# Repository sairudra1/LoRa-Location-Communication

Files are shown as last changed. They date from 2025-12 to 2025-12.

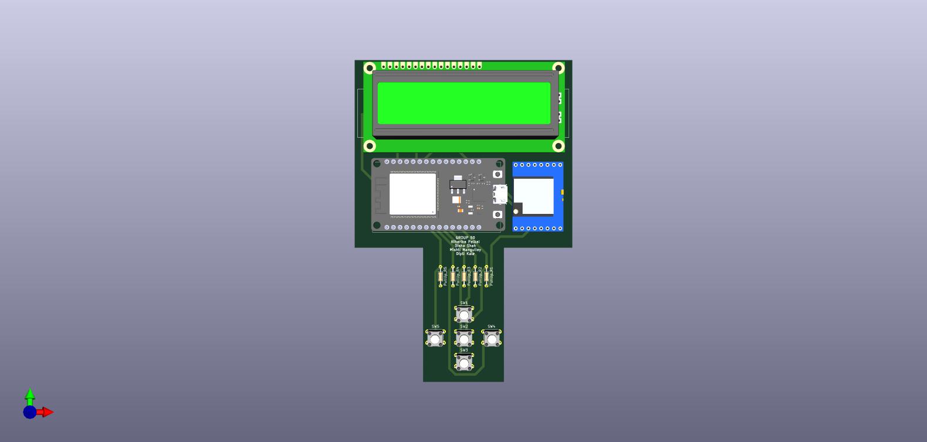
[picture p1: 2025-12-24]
LoRa_SX1278_PCB/LoRa_SX1278_PCB.jpg

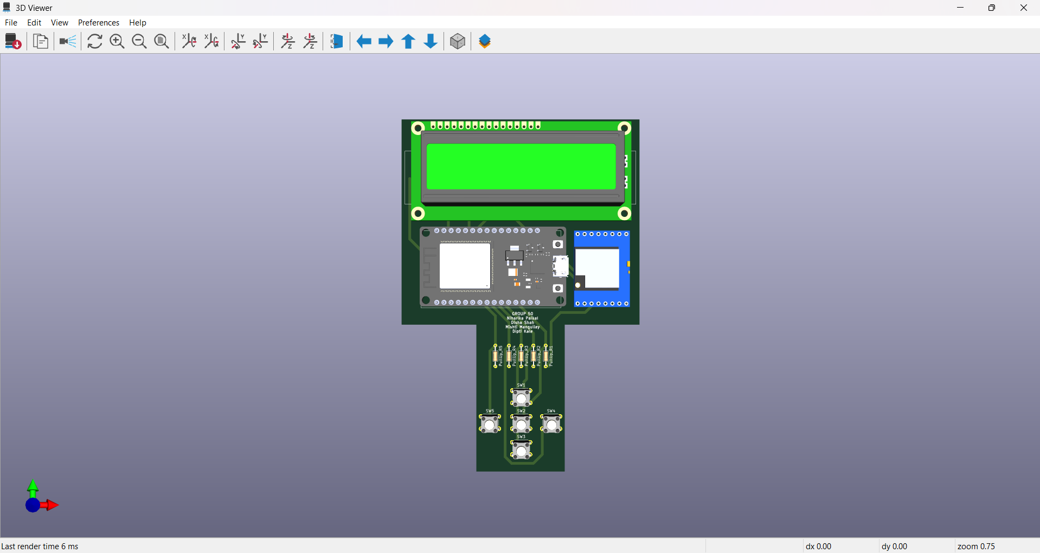
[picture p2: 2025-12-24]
LoRa_SX1278_PCB/Screenshot 2025-11-09 223550.png

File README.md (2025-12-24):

# 📡 LoRa Location Communication System

**Solution for SIH 2025**  
**Problem Statement ID:** 25255  

A low-power, long-range **LoRa-based location and communication system** designed using **ESP32 and SX1278**, with a mobile application interface built using **MIT App Inventor**.

## 🧩 Key Features

- 📡 Long-range LoRa communication
- 🔋 Low-power system design
- 📍 Location-based data transmission
- 📱 Android app interface
- 🛠️ Custom PCB design
- 🔄 Reliable peer-to-peer communication

## 🛠️ Tech Stack

### Hardware
- ESP32 Dev Board
- LoRa SX1278 Module
- Custom PCB
- 16x2 LCD Display
- Buttons

### Software
- Arduino IDE (ESP32 firmware)
- MIT App Inventor (Android App)
- draw.io (Block Diagrams)
Structure

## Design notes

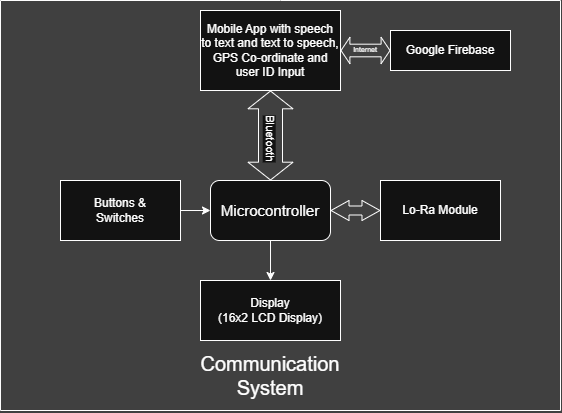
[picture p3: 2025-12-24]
1system.drawio.png

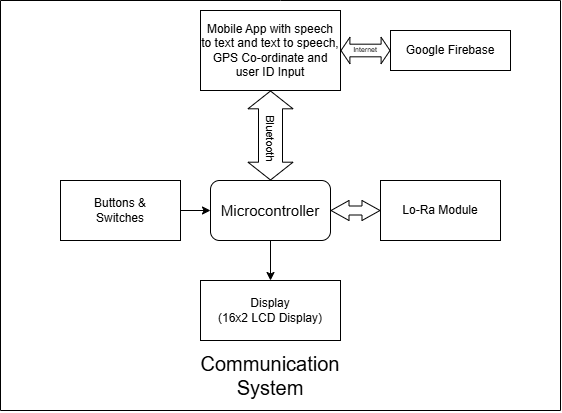
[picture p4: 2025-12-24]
2system.drawio.png

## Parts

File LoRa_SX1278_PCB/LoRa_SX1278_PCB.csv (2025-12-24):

Reference | Qty | Value | DNP | Exclude from BOM | Exclude from Board | Footprint | Datasheet
BT1 | 1 | Battery |  |  |  | Connector_PinHeader_2.54mm:PinHeader_1x02_P2.54mm_Vertical | ~
J1 | 1 | I2C MODULE |  |  |  | Connector_PinHeader_2.54mm:PinHeader_1x04_P2.54mm_Vertical | ~
PullUp_R1,PullUp_R2,PullUp_R3,PullUp_R4,PullUp_R5 | 5 | 100K |  |  |  | Resistor_THT:R_Axial_DIN0204_L3.6mm_D1.6mm_P7.62mm_Horizontal | ~
SW1,SW2,SW3,SW4,SW5 | 5 | SW_SPST |  |  |  | Button_Switch_THT:SW_TH_Tactile_Omron_B3F-100x | ~
U1 | 1 | LoRa SX1278 |  |  |  | LoRa_SX1278_:LoRa_SX1278
U2 | 1 | ~ |  |  |  | esp32devkitv1:ESP32DEVIKITV1

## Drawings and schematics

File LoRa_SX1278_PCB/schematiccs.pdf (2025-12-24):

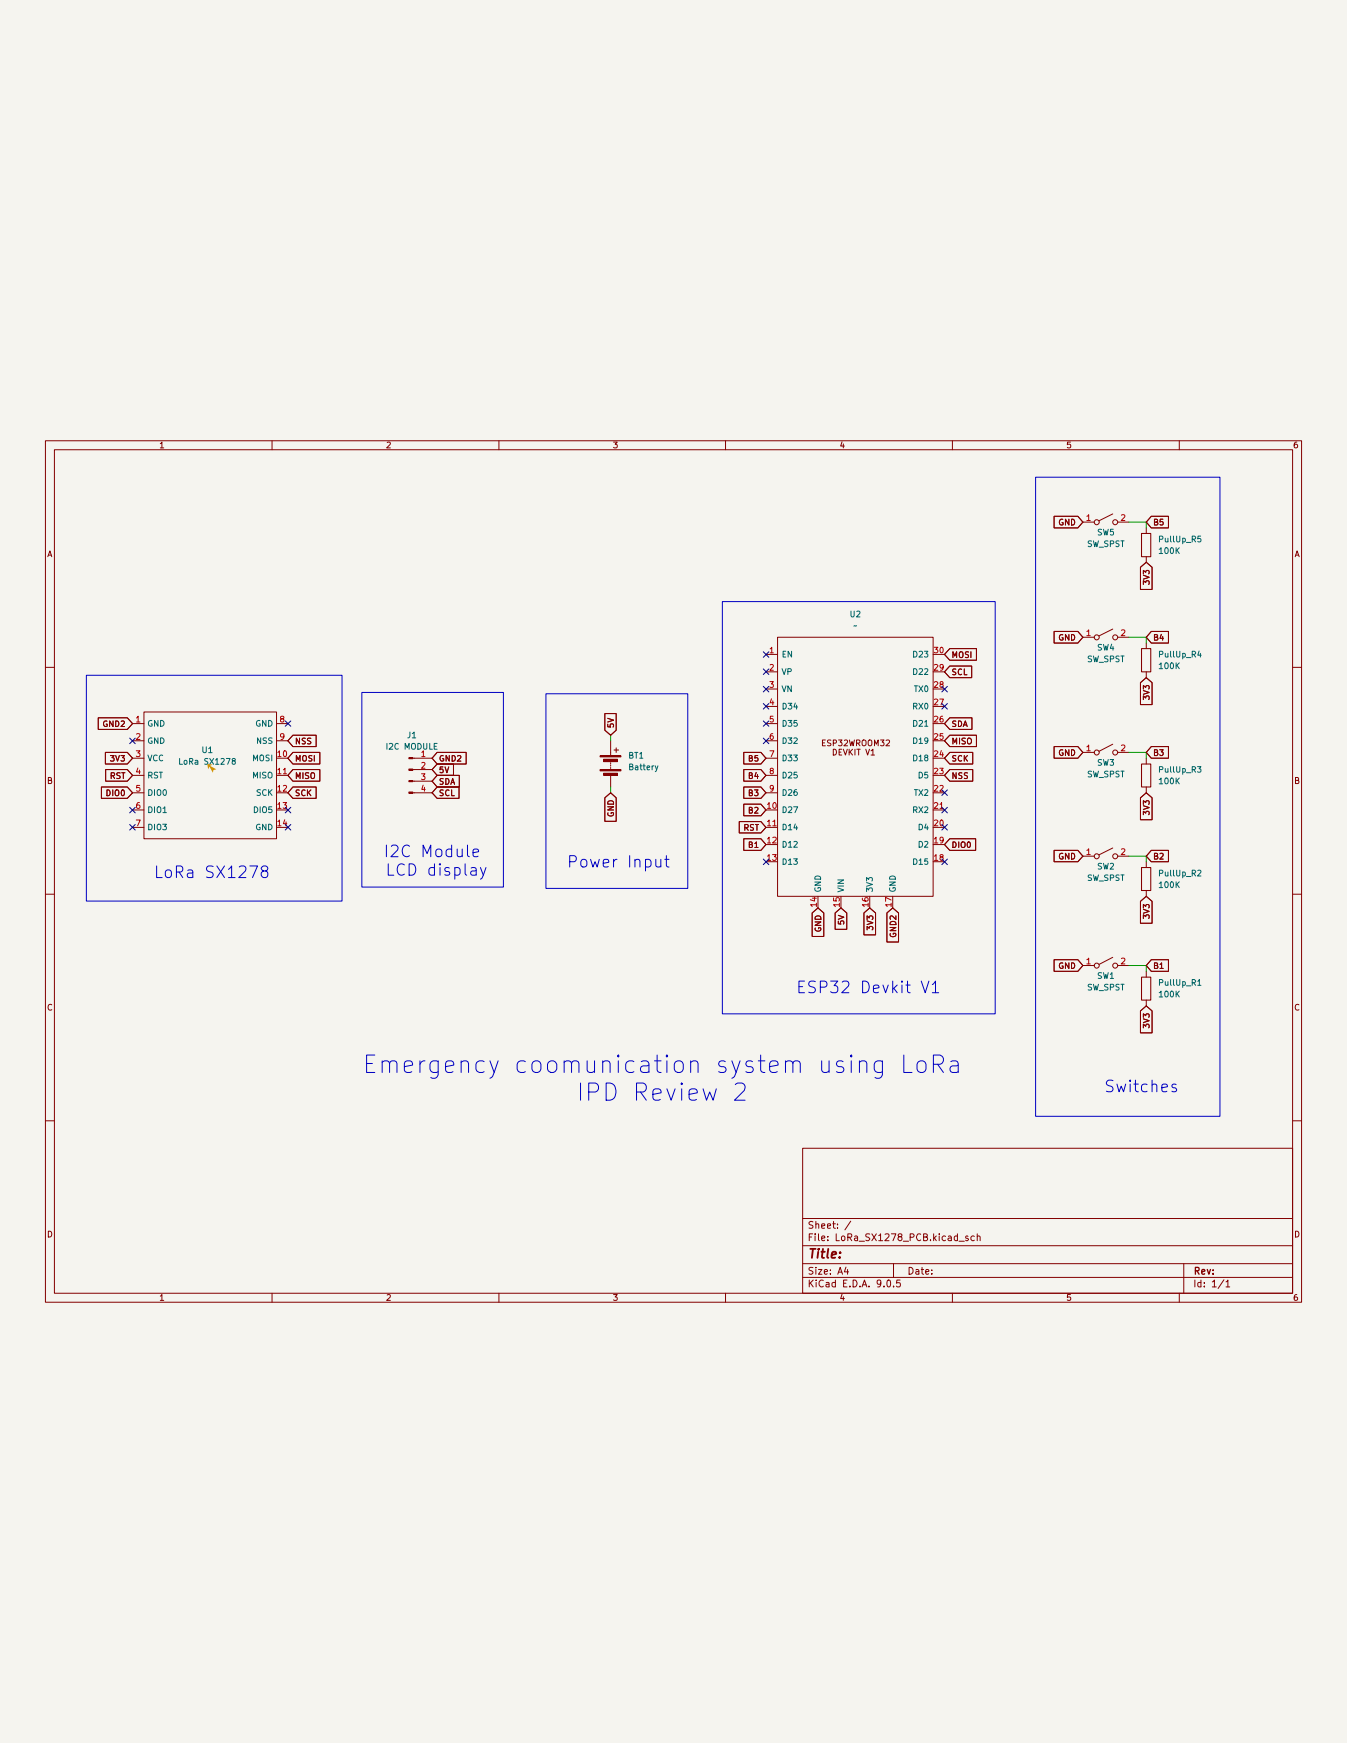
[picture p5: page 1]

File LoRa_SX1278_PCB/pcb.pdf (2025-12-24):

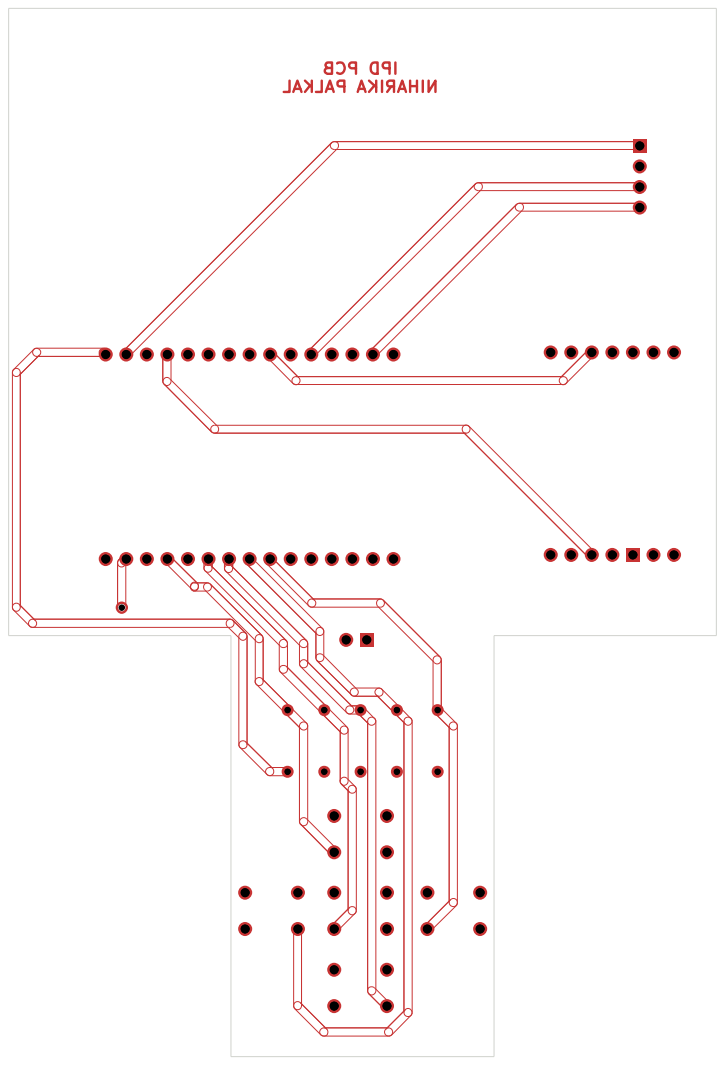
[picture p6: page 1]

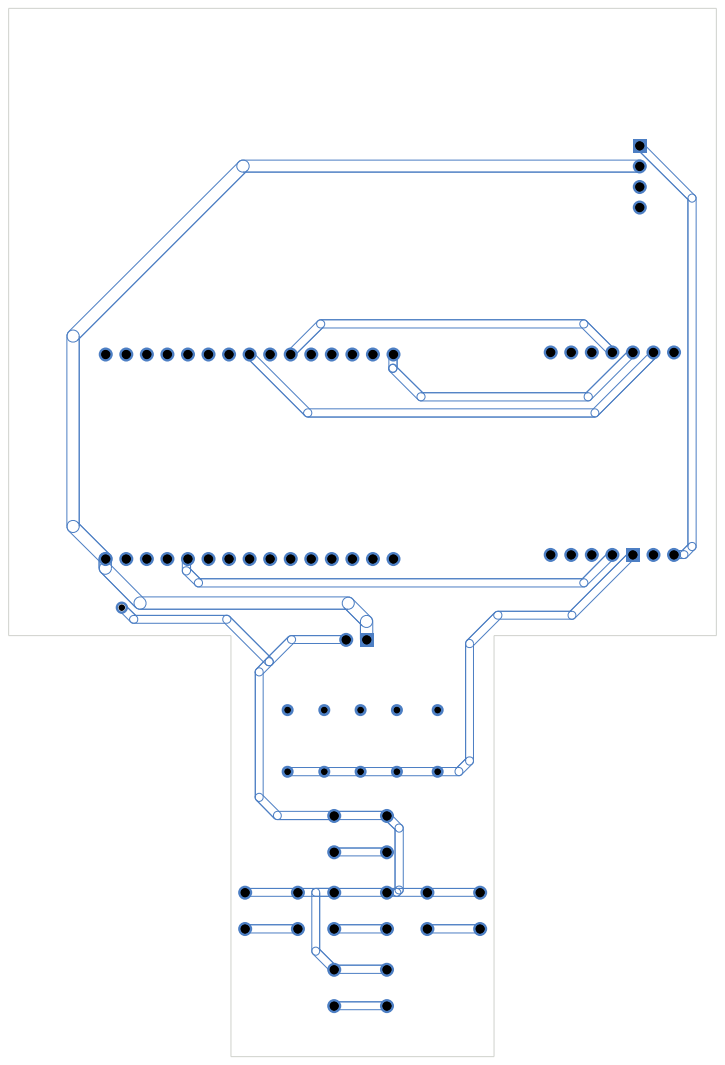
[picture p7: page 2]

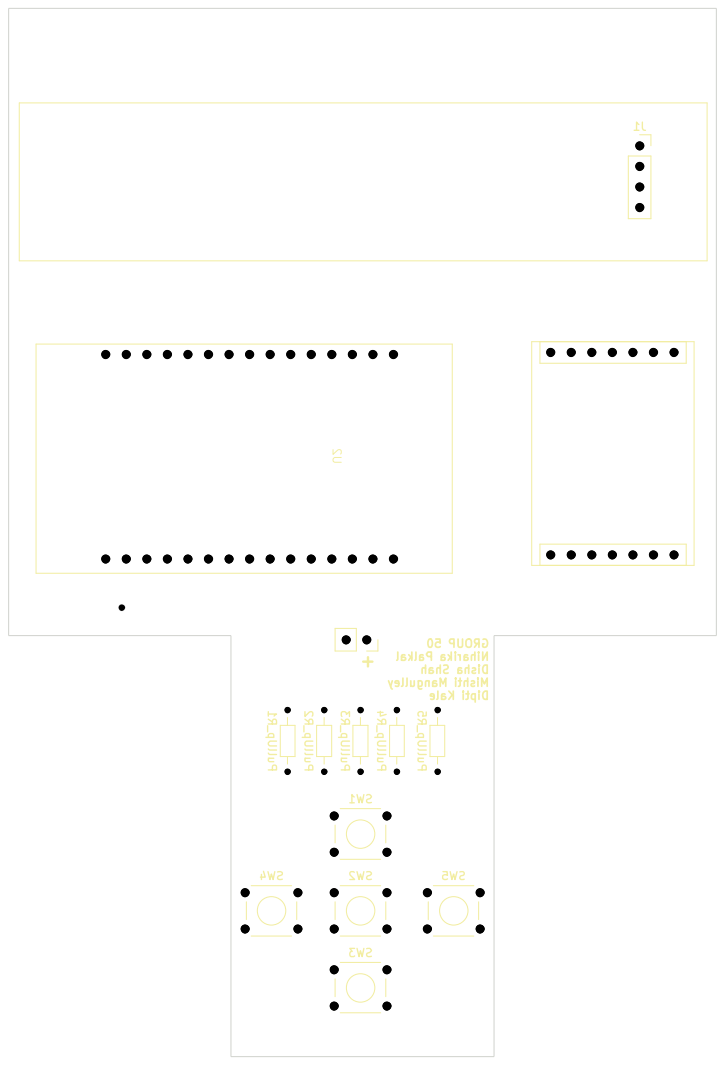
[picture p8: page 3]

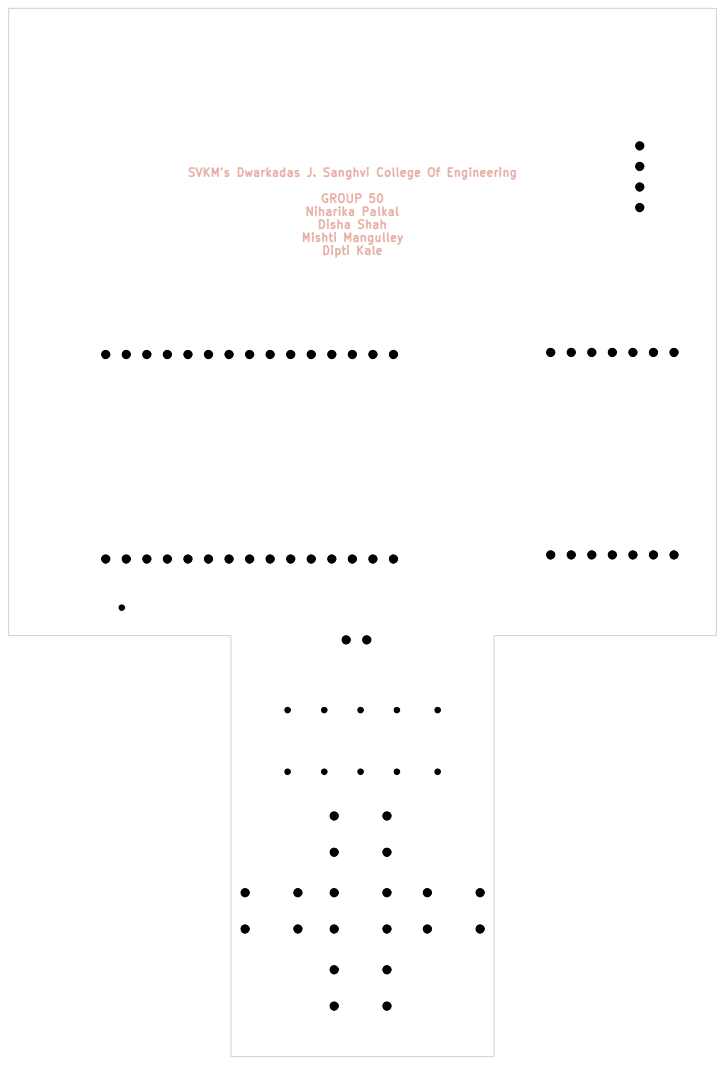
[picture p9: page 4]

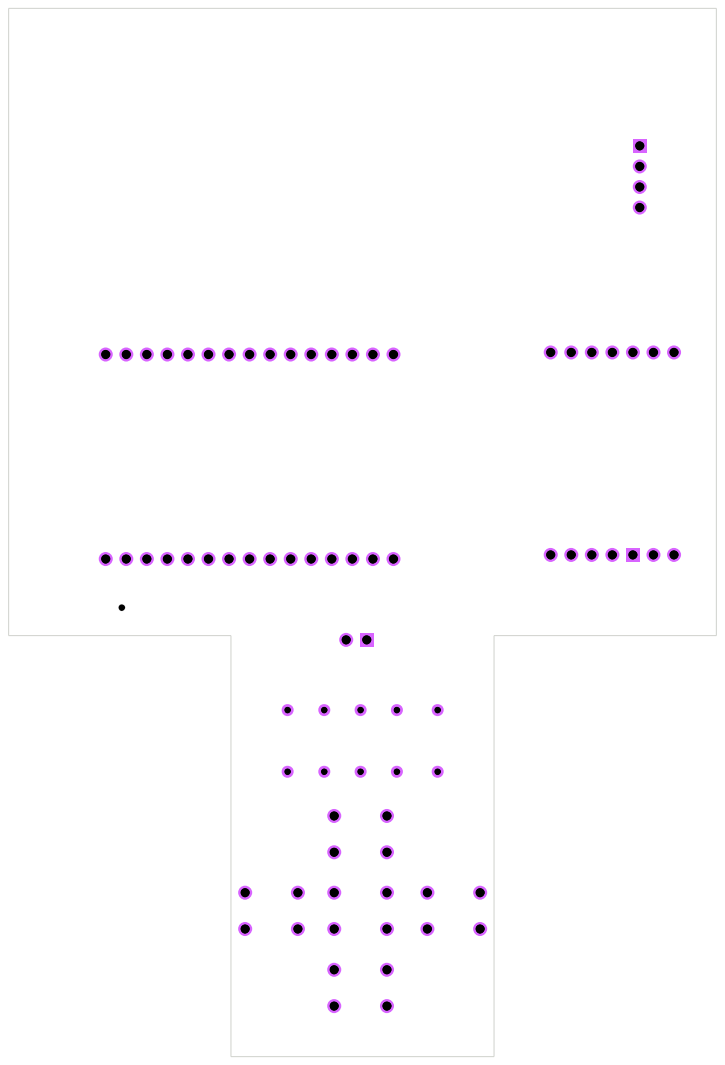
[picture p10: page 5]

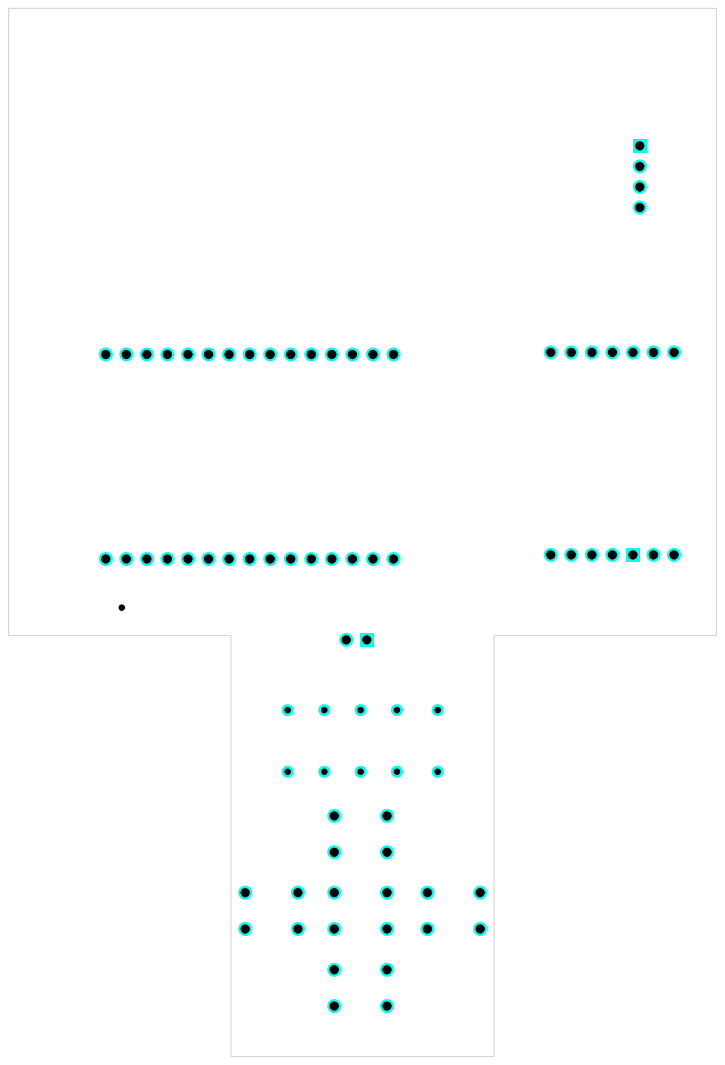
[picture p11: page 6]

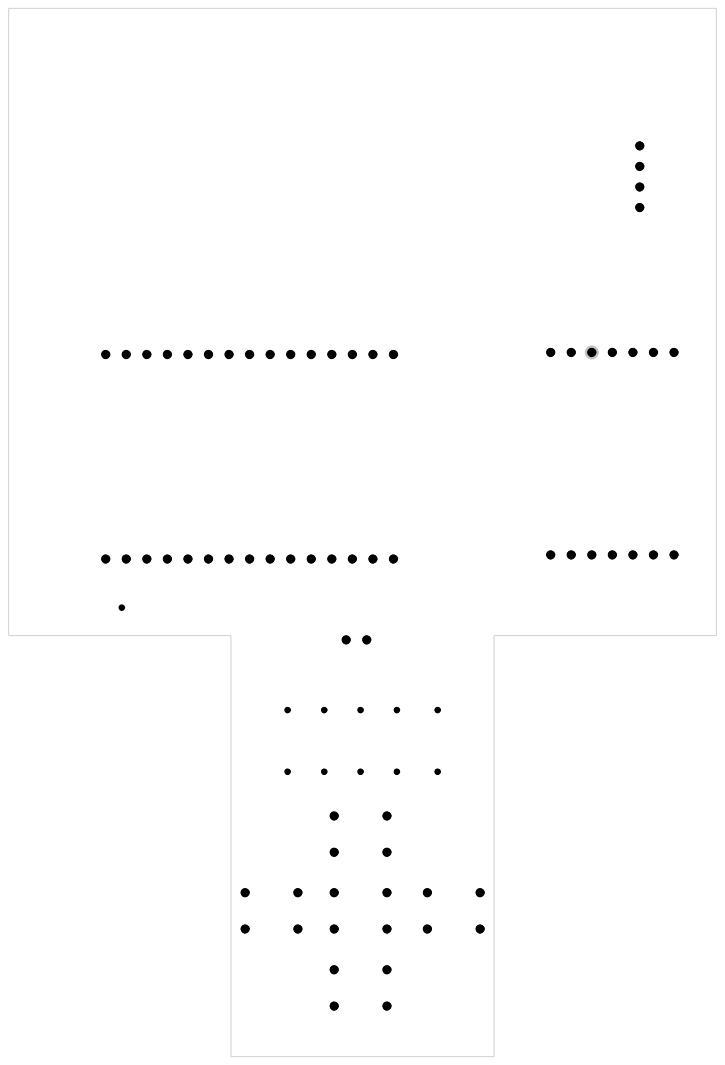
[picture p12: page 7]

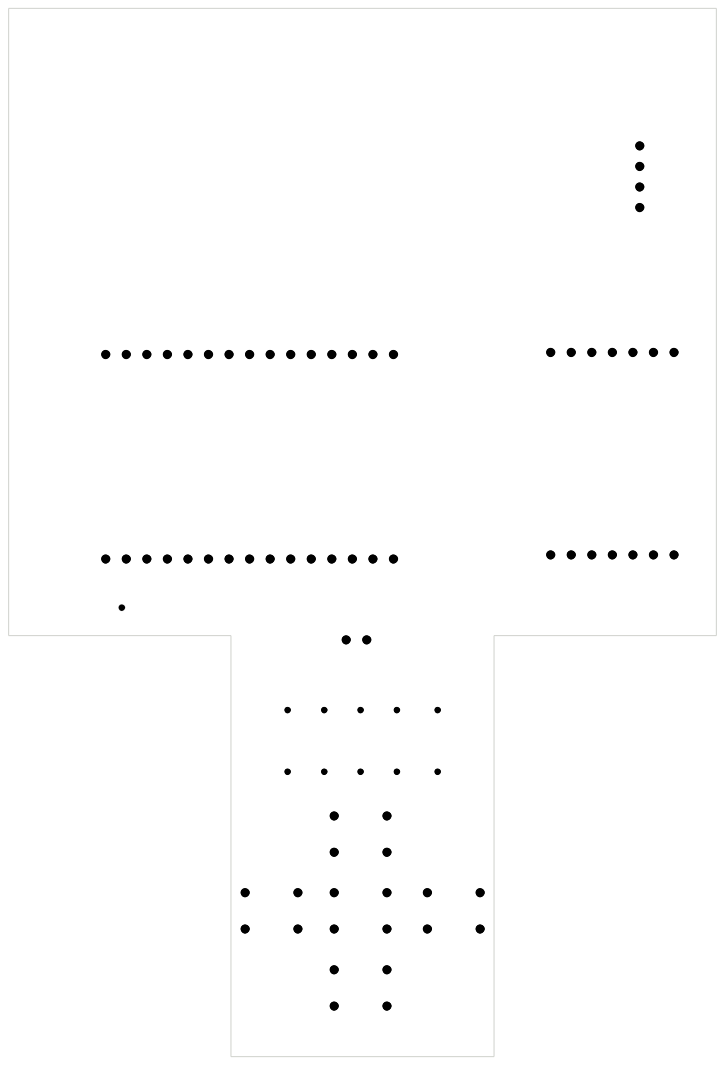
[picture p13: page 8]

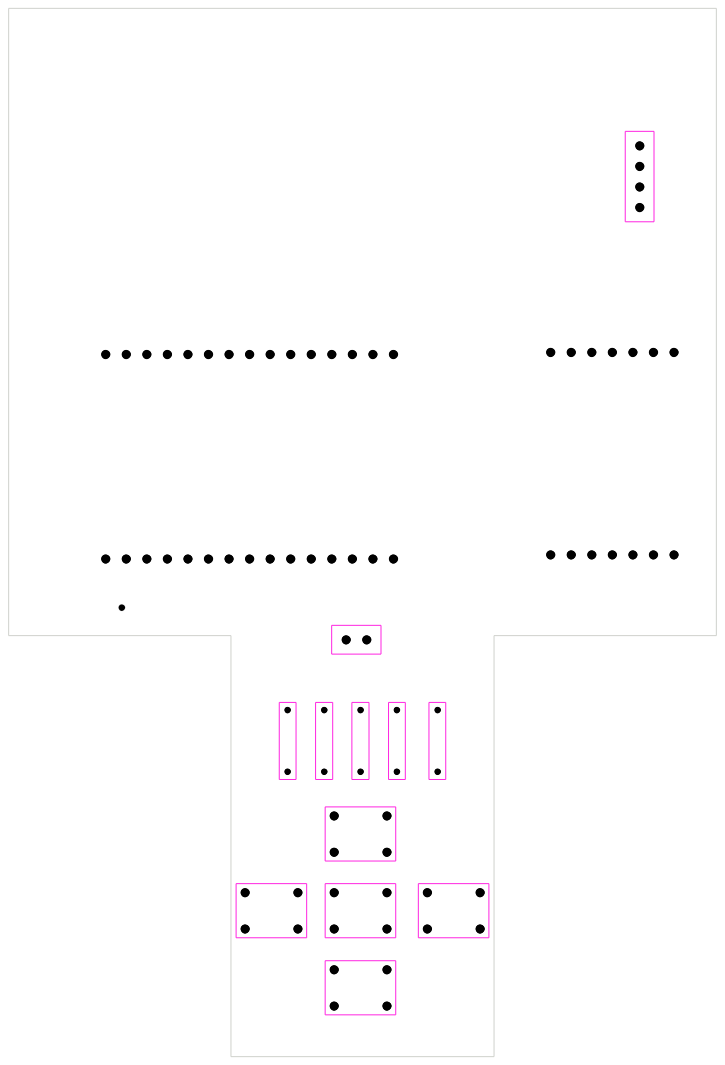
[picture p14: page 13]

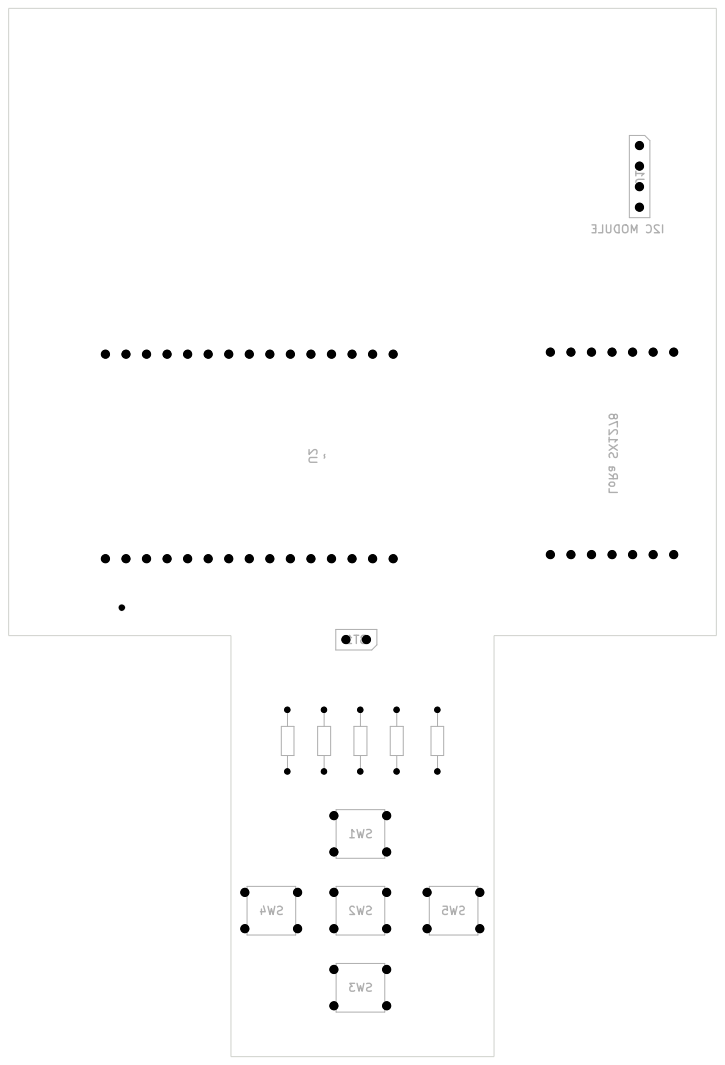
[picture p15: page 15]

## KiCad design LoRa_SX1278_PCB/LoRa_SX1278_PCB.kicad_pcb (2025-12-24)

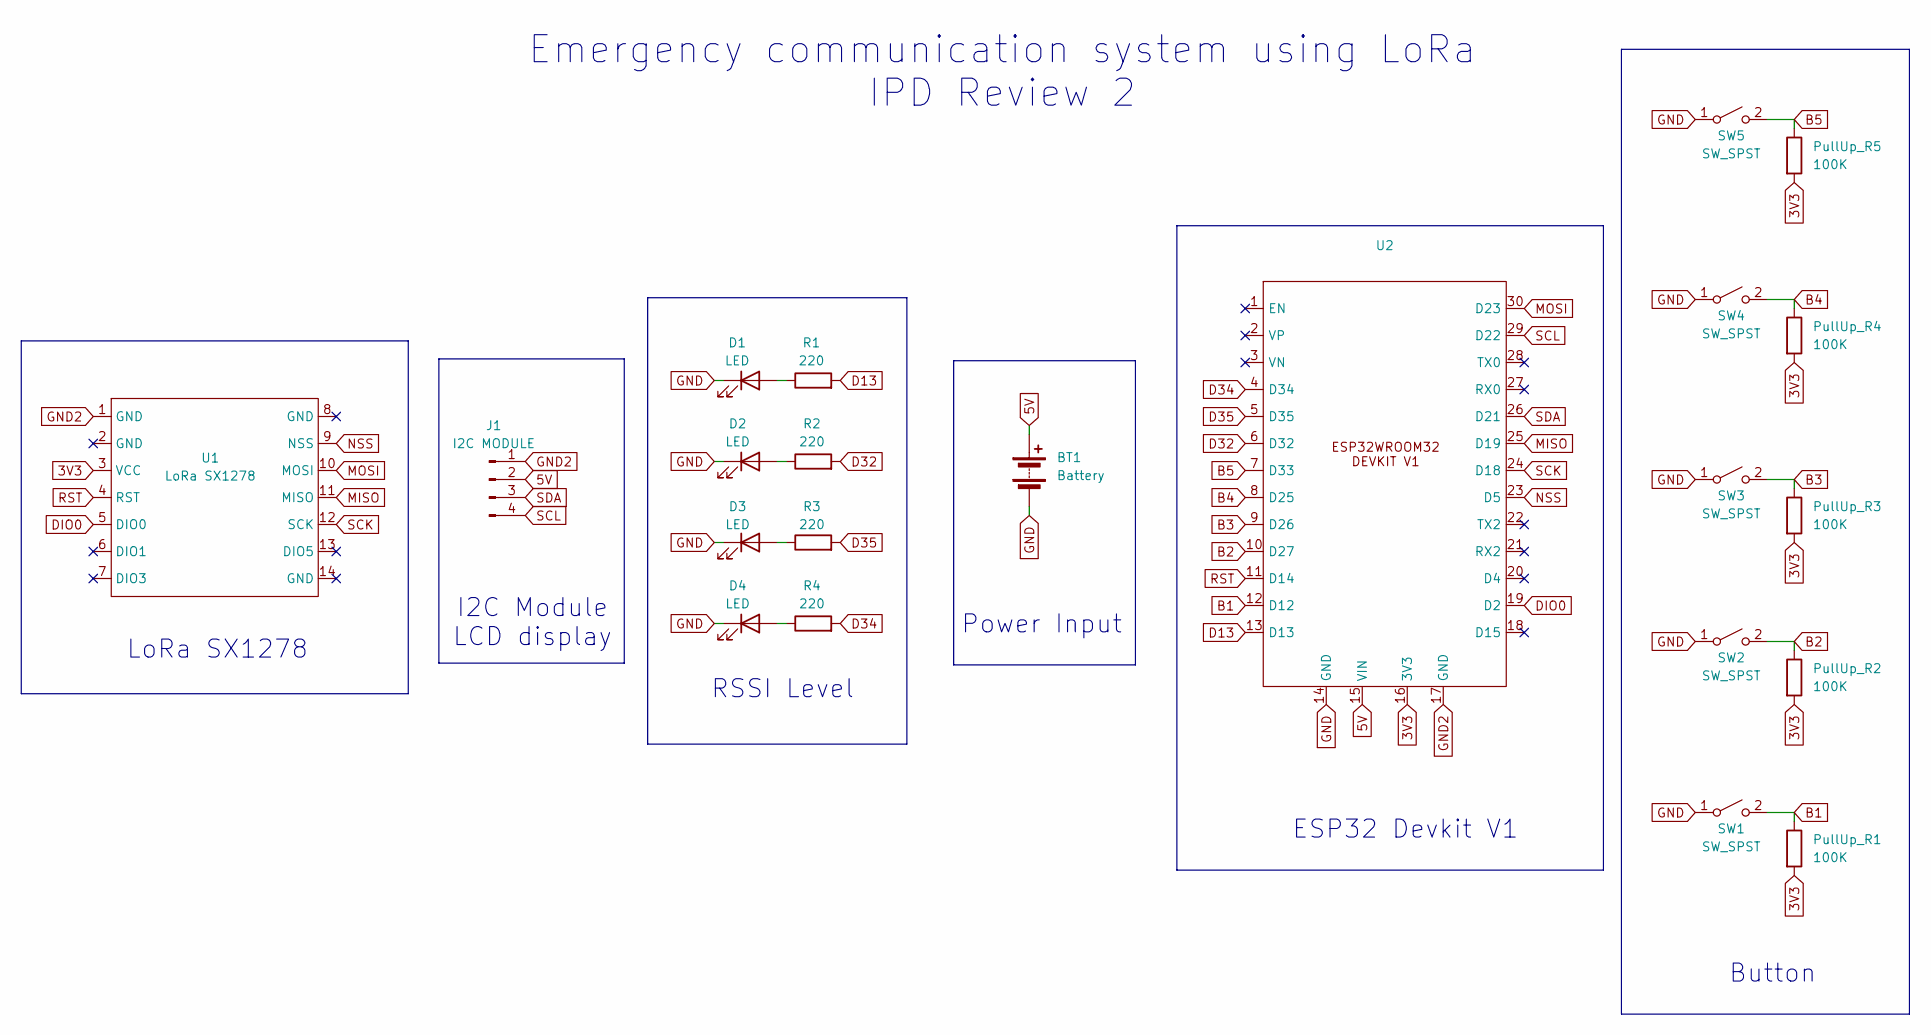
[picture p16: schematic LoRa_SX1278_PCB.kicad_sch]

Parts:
BT1: Battery; PinHeader_1x02_P2.54mm_Vertical
D1, D2, D3, D4: LED; LED_D3.0mm_Horizontal_O3.81mm_Z2.0mm
J1: I2C MODULE; PinHeader_1x04_P2.54mm_Vertical
PullUp_R1, PullUp_R2, PullUp_R3, PullUp_R4, PullUp_R5: 100K; R_Axial_DIN0204_L3.6mm_D1.6mm_P7.62mm_Horizontal
R1, R2, R3, R4: 220; R_Axial_DIN0204_L3.6mm_D1.6mm_P7.62mm_Horizontal
SW1, SW2, SW3, SW4, SW5: SW_SPST; SW_TH_Tactile_Omron_B3F-100x
U1: LoRa SX1278; LoRa_SX1278
U2: ESP32DEVIKITV1

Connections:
3V3: PullUp_R1.2, PullUp_R2.2, PullUp_R3.2, PullUp_R4.2, PullUp_R5.2, U1.3 (VCC), U2.16 (3V3)
5V: BT1.1 (+), J1.2, U2.15 (VIN)
B1: PullUp_R1.1, SW1.2 (B), U2.12 (D12)
B2: PullUp_R2.1, SW2.2 (B), U2.10 (D27)
B3: PullUp_R3.1, SW3.2 (B), U2.9 (D26)
B4: PullUp_R4.1, SW4.2 (B), U2.8 (D25)
B5: PullUp_R5.1, SW5.2 (B), U2.7 (D33)
D13: R1.2, U2.13 (D13)
D32: R2.2, U2.6 (D32)
D34: R4.2, U2.4 (D34)
D35: R3.2, U2.5 (D35)
DIO0: U1.5 (DIO0), U2.19 (D2)
GND: BT1.2 (-), D1.1 (K), D2.1 (K), D3.1 (K), D4.1 (K), SW1.1 (A), SW2.1 (A), SW3.1 (A), SW4.1 (A), SW5.1 (A), U2.14 (GND)
GND2: J1.1, U1.1 (GND), U2.17 (GND)
MISO: U1.11 (MISO), U2.25 (D19)
MOSI: U1.10 (MOSI), U2.30 (D23)
NSS: U1.9 (NSS), U2.23 (D5)
unnamed: D1.2 (A), R1.1
unnamed: D2.2 (A), R2.1
unnamed: D3.2 (A), R3.1
unnamed: D4.2 (A), R4.1
RST: U1.4 (RST), U2.11 (D14)
SCK: U1.12 (SCK), U2.24 (D18)
SCL: J1.4, U2.29 (D22)
SDA: J1.3, U2.26 (D21)

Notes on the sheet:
Emergency communication system using LoRa IPD Review 2
LoRa SX1278
ESP32 Devkit V1
Power Input
RSSI Level
Button
I2C Module LCD display

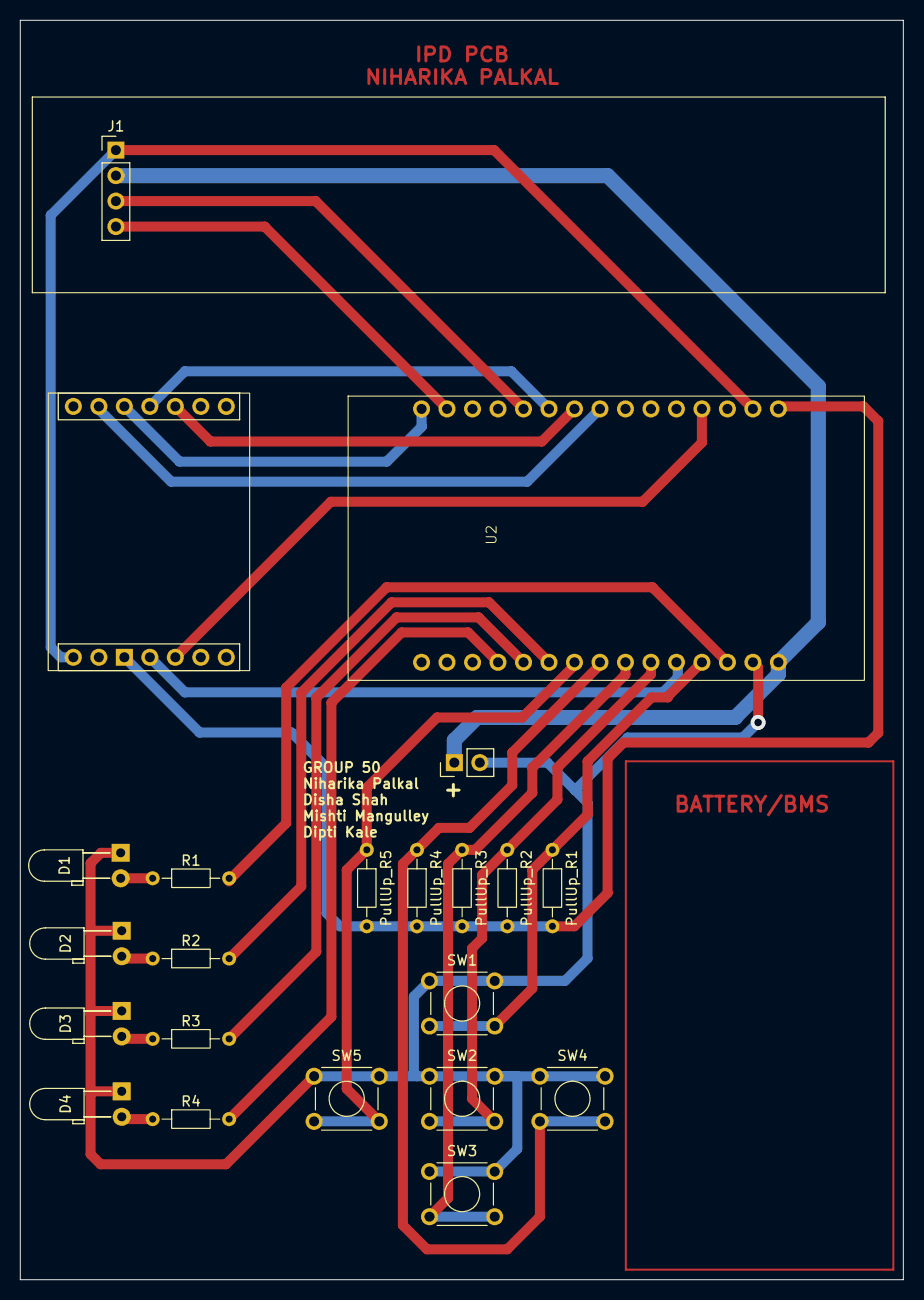
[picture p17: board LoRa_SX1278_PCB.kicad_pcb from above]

Board: 2 copper layers, 88.0 x 125.5 mm, 22 parts (0 on the bottom side), 25 nets.

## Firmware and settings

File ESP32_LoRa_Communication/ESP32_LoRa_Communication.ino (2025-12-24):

#include <SPI.h>
#include <LoRa.h>
#include "BluetoothSerial.h"

// Create a Bluetooth Serial object
BluetoothSerial BTSerial;

// Define LoRa pins
#define ss 5
#define rst 14
#define dio0 2

void setup() {
  Serial.begin(115200);
  while (!Serial);
  Serial.println("LoRa + Bluetooth Bridge");

  // Start Bluetooth
  BTSerial.begin("ESP32_LoRa_BT");
  Serial.println("Bluetooth started. Pair and connect.");

  // Setup LoRa
  LoRa.setPins(ss, rst, dio0);
  while (!LoRa.begin(433E6)) {
    Serial.println("Starting LoRa failed!");
    delay(500);
  }
  LoRa.setSyncWord(0xAB); // Must match with sender/receiver
  Serial.println("LoRa Initialized Successfully!");
}

void loop() {
  // 🔸 1. Check if LoRa received something
  int packetSize = LoRa.parsePacket();
  if (packetSize) {
    Serial.print("Received LoRa packet: ");
    BTSerial.print("Received LoRa packet: ");

    String LoRaData = "";
    while (LoRa.available()) {
      LoRaData += (char)LoRa.read();
    }

    Serial.print(LoRaData);
    BTSerial.print(LoRaData);

    Serial.print(" | RSSI: ");
    Serial.println(LoRa.packetRssi());
    //BTSerial.print(";");
    BTSerial.println(LoRa.packetRssi());
  }

  // 🔸 2. Check if Bluetooth received something
  if (BTSerial.available()) {
    String BTData = BTSerial.readStringUntil('\n'); // Read until newline
    BTData.trim(); // Remove unwanted spaces/newlines

    if (BTData.length() > 0) {
      Serial.print("Sending via LoRa: ");
      Serial.println(BTData);

      LoRa.beginPacket();
      LoRa.print(BTData);
      LoRa.endPacket();

      Serial.println("LoRa transmission done!");
    }
  }
}

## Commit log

2025-12-24 PCB Files
    [LoRa_SX1278_PCB.csv, LoRa_SX1278_PCB.kicad_pcb, LoRa_SX1278_PCB.kicad_sch]
2025-12-24 ESP32 Code
